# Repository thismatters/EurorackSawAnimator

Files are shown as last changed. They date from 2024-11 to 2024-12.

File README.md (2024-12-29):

# Saw Animator

```
     |\
<--> | \ | <-->
        \|
```

The Saw Animator combines a signal from an LFO with a saw audio signal to produce interesting overtones. In effect the LFO modulates the frequency of the saw wave causing the waveform to dance side-to-side on the oscilloscope. This module has an LFO of its own with adjustable rate, this can be overridden with a different CV signal.

The circuit here is based on the [Yusynth Saw Animator](https://yusynth.net/Modular/EN/SAWANIM/index.html) with minor tweaks to make it more Eurorack friendly. The changes I've made are thus:
* Selected resistors appropriate for +/-12V rails,
* Added polarity protection so that a backward power header doesn't fry anything (twin series schotty diodes: BAT54SL),
* Full surface mount design.

The Yusynth page is a treasure trove of information about this circuit that I am too amateur to claim as my own; please read that outstanding page before using this circuit. The page provides many details and other implementations of this circuit that you may find suitable.

The KiCAD project here uses the library/footprints [found in my companion repo](https://github.com/thismatters/EurorackKiCAD).

## Width

10hp on an Intellijel 1U rack.

## Inputs

Single potentiometer for adjusting LFO rate. Input jack for control voltage which overrides the LFO. Input jack for saw audio signal.

## Outputs

Output jack for animated saw output. LED which tracks the internal LFO.

## Adjustment

### Refine shape

- Ground the LFO input
- Connect a balanced saw wave (+/-5V) to the input
- Connect oscilloscope to the output
- Adjust RV2 (the one in the middle layer) until the triangle looks smooth

###  Set Balance

- Adjust RV1 so that the output is blanaced in the +/-5V range.

## Vendors

There are part numbers in the [BOM](saw-animator.csv) for many of the parts (not for basic passives though) at the following vendors:

* [Mouser](https://www.mouser.com): Needs no introduction. Get your ICs from here (or [digikey](https://www.digikey.com)).
* [Tayda Electronics](https://www.taydaelectronics.com/): Good supplier for passive components; audio jacks, and potentiometers. Their audio jacks are slightly smaller than the thonkiconn from thonk.
* [Love My Switches](https://lovemyswitches.com/): Has [really good knobs](https://lovemyswitches.com/anodized-aluminum-knob-the-lo-fi-1-4-smooth-shaft-12-5mm-od/) to go on those potentiometers!
* [OSHPark](https://oshpark.com/): Fast and (relatively) cheap PCB manufacturer. [V0 PCB](https://oshpark.com/shared_projects/MXBVaxpS)

## Issues

### V0
- The output saw waveshape is slightly distorted at the bottom, the slope is a little off
- Assembly was harder than necessary because the two boards with SMD components did not have enough support tabs to keep them together; each board had to be registered for solder paste application separately.

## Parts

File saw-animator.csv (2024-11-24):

# | Reference | Qty | Value | Footprint | DNP | Vendor | PartNum
1 | C1, C2 | 2 | 22u 50V | Capacitor_THT:CP_Radial_D5.0mm_P2.50mm
2 | C3, C5 | 2 | 100n | Capacitor_SMD:C_0805_2012Metric
3 | C4 | 1 | 100p | Capacitor_SMD:C_0805_2012Metric
4 | C6 | 1 | 2.2u box | Capacitor_THT:C_Rect_L7.2mm_W7.2mm_P5.00mm_FKS2_FKP2_MKS2_MKP2
5 | D1, D2 | 2 | BAT54S | Package_TO_SOT_SMD:SOT-23 |  | Mouser | 863-BAT54SLT1G
6 | D3, D4, D5, D7 | 4 | 1N4148 | Diode_SMD:D_SOD-323_HandSoldering
7 | D6 | 1 | LED_GREEN | LED_THT:LED_D3.0mm
8 | J1 | 1 | Conn_02x05_Odd_Even | Eurorack:PinHeader_2x05_P2.54mm_Vertical |  | Tayda | A-2939
9 | J2, J3, J4 | 3 | Conn_01x03_Socket | Connector_PinSocket_2.54mm:PinSocket_1x03_P2.54mm_Vertical
10 | J5, J6, J7 | 3 | Conn_01x03_Pin | Connector_PinHeader_2.54mm:PinHeader_1x03_P2.54mm_Vertical
11 | J8, J9, J10 | 3 | AudioJack2_SwitchT | Eurorack:AudioJack2_Tayda_A-2566 |  | Tayda | A-2566
12 | Q1 | 1 | BC547 | Package_TO_SOT_THT:TO-92_Inline_Wide |  | Mouser | 637-BC547C
13 | R1, R2 | 2 | 10 | Resistor_SMD:R_0805_2012Metric
14 | R3, R4, R5, R6, R24, R25 | 6 | 100K | Resistor_SMD:R_0805_2012Metric
15 | R7, R8, R9 | 3 | 47K | Resistor_SMD:R_0805_2012Metric
16 | R10, R11, R13, R18 | 4 | 150K | Resistor_SMD:R_0805_2012Metric
17 | R12, R21, R23 | 3 | 22K | Resistor_SMD:R_0805_2012Metric
18 | R14 | 1 | 1K | Resistor_SMD:R_0805_2012Metric
19 | R15 | 1 | 120K | Resistor_SMD:R_0805_2012Metric
20 | R16 | 1 | 220K | Resistor_SMD:R_0805_2012Metric
21 | R17, R20 | 2 | 15K | Resistor_SMD:R_0805_2012Metric
22 | R19 | 1 | 1.5K | Resistor_SMD:R_0805_2012Metric
23 | R22 | 1 | 4.7K | Resistor_SMD:R_0805_2012Metric
24 | RV1 | 1 | 100K | Potentiometer_THT:Potentiometer_Bourns_3296W_Vertical
25 | RV2 | 1 | C1M | Eurorack:Potentiometer_RV16AF-41-15R1
26 | RV3 | 1 | 500K | Potentiometer_THT:Potentiometer_Bourns_3006P_Horizontal
27 | U1, U2 | 2 | TL074 | Package_SO:SOIC-14_3.9x8.7mm_P1.27mm |  | Mouser | 595-TL074CDR

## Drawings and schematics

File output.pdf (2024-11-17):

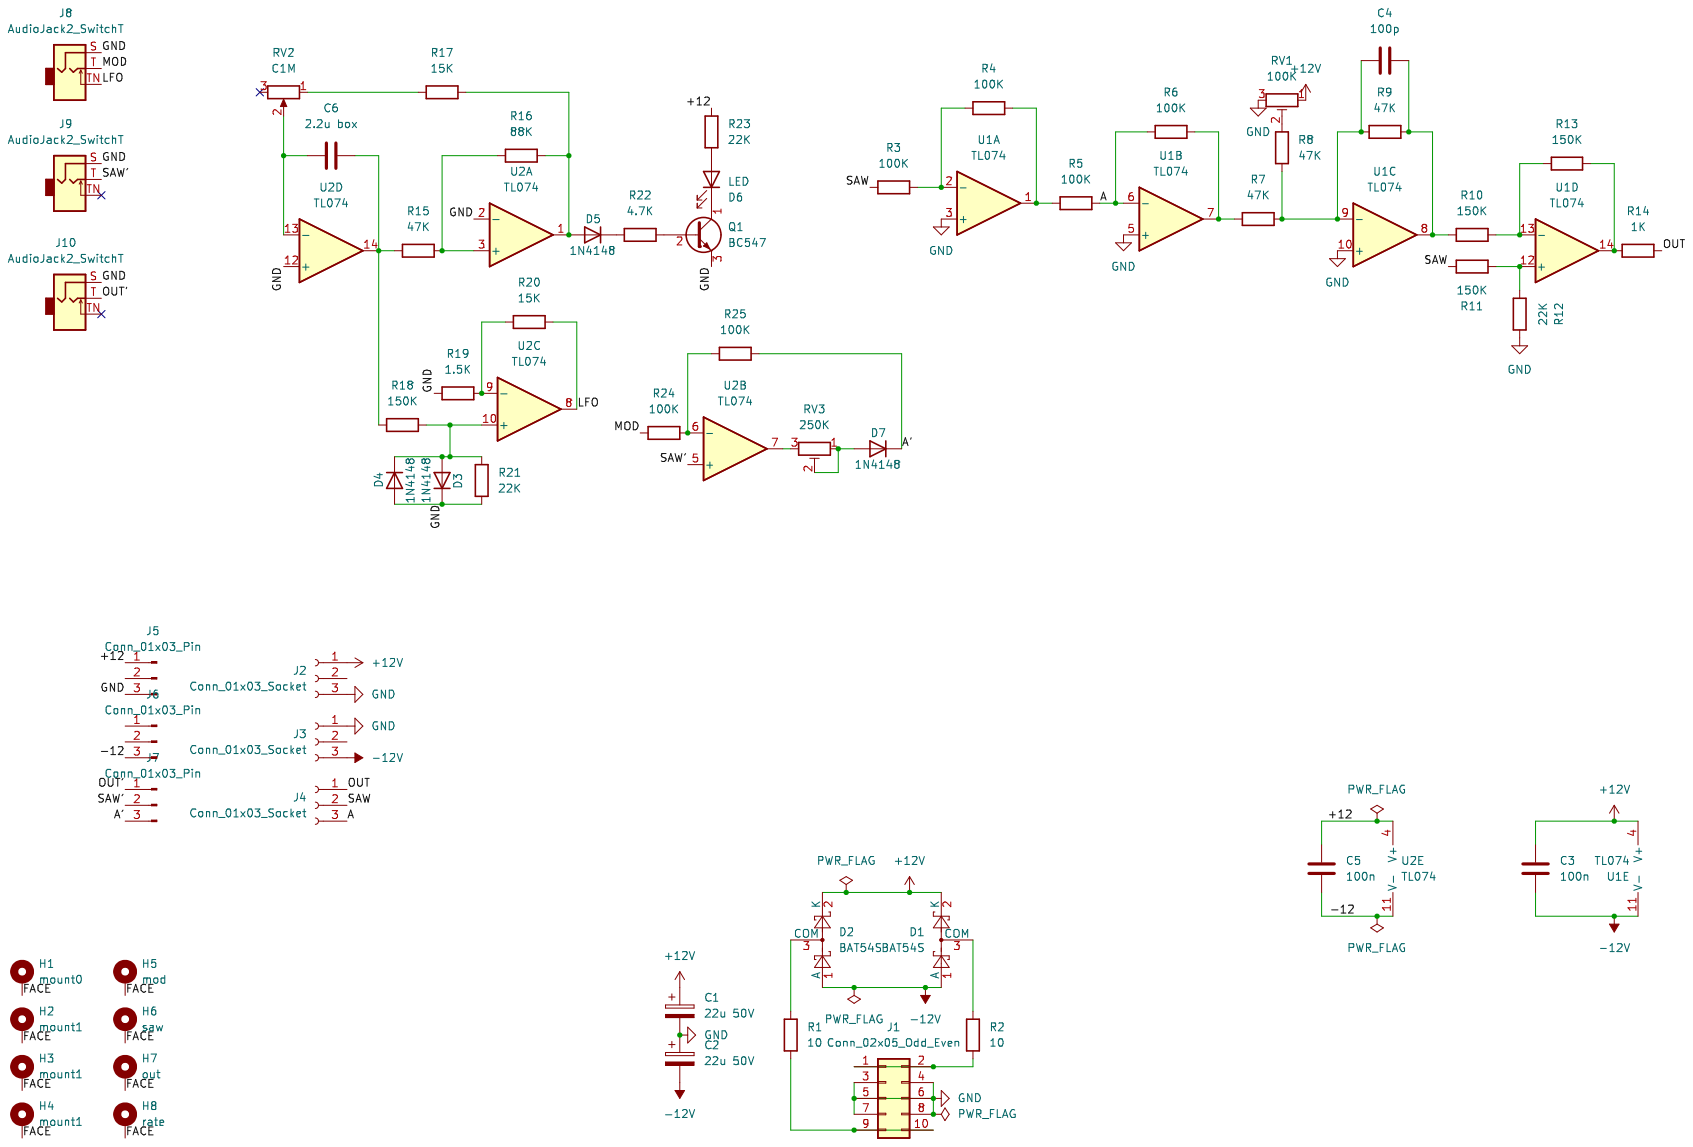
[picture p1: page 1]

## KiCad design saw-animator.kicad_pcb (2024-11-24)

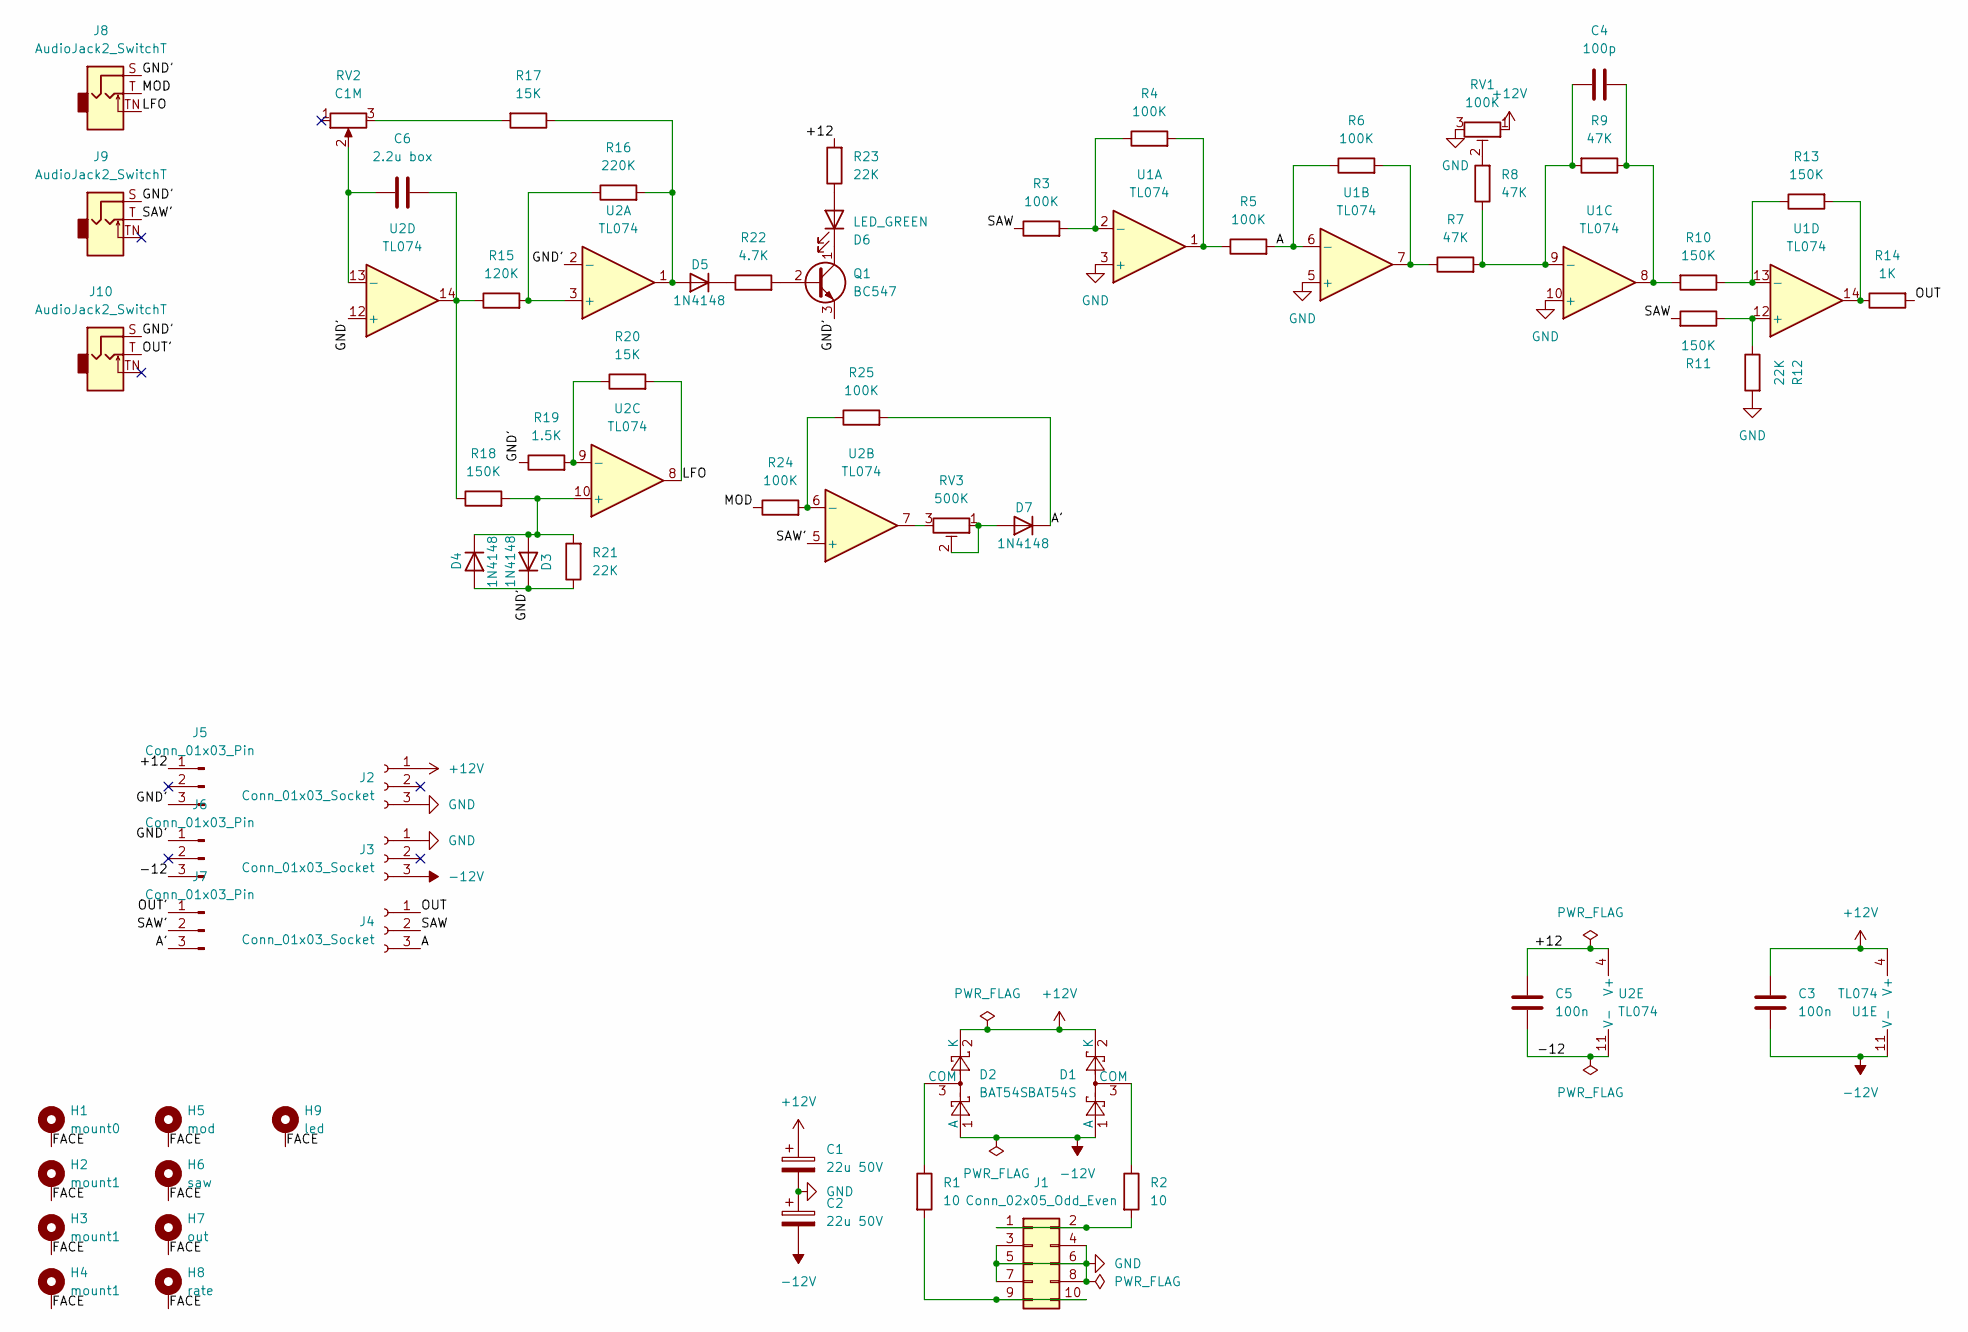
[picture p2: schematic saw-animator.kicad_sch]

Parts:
C1, C2: 22u 50V; CP_Radial_D5.0mm_P2.50mm
C3, C5: 100n; C_0805_2012Metric
C4: 100p; C_0805_2012Metric
C6: 2.2u box; C_Rect_L7.2mm_W7.2mm_P5.00mm_FKS2_FKP2_MKS2_MKP2
D1, D2: BAT54S; SOT-23; PartNum 863-BAT54SLT1G
D3, D4, D5, D7: 1N4148; D_SOD-323_HandSoldering
D6: LED_GREEN; LED_D3.0mm
H1: mount0; Mech-MountingHole
H2, H3, H4: mount1; Mech-MountingHole
H5: mod; Mech-AudioJack-Hole-Input-CV
H6: saw; Mech-AudioJack-Hole-Input
H7: out; Mech-AudioJack-Hole-Output
H8: rate; Mech-Potentiometer-Hole_level_90deg
H9: led; Mech-LED-Hole-3mm-Bezel
J1: Conn_02x05_Odd_Even; PinHeader_2x05_P2.54mm_Vertical; PartNum A-2939
J2, J3, J4: Conn_01x03_Socket; PinSocket_1x03_P2.54mm_Vertical
J5, J6, J7: Conn_01x03_Pin; PinHeader_1x03_P2.54mm_Vertical
J8, J9, J10: AudioJack2_SwitchT; AudioJack2_Tayda_A-2566; PartNum A-2566
Q1: BC547; TO-92_Inline_Wide; PartNum 637-BC547C
R1, R2: 10; R_0805_2012Metric
R3, R4, R5, R6, R24, R25: 100K; R_0805_2012Metric
R7, R8, R9: 47K; R_0805_2012Metric
R10, R11, R13, R18: 150K; R_0805_2012Metric
R12, R21, R23: 22K; R_0805_2012Metric
R14: 1K; R_0805_2012Metric
R15: 120K; R_0805_2012Metric
R16: 220K; R_0805_2012Metric
R17, R20: 15K; R_0805_2012Metric
R19: 1.5K; R_0805_2012Metric
R22: 4.7K; R_0805_2012Metric
RV1: 100K; Potentiometer_Bourns_3296W_Vertical
RV2: C1M; Potentiometer_RV16AF-41-15R1
RV3: 500K; Potentiometer_Bourns_3006P_Horizontal
U1, U2: TL074; SOIC-14_3.9x8.7mm_P1.27mm; PartNum 595-TL074CDR

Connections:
+12V: C1.1, C3.1, D1.2 (K), D2.2 (K), J2.1, RV1.1, U1.4 (V+)
-12V: C2.2, C3.2, D1.1 (A), D2.1 (A), J3.3, U1.11 (V-)
/+12: C5.1, J5.1, R23.2, U2.4 (V+)
/-12: C5.2, J6.3, U2.11 (V-)
/A: J4.3, R5.2, R6.1, U1.6 (-)
/A': D7.1 (K), J7.3, R25.2
/FACE: H1.1, H2.1, H3.1, H4.1, H5.1, H6.1, H7.1, H8.1, H9.1
/GND': D3.1 (K), D4.2 (A), J5.3, J6.1, J8.S, J9.S, J10.S, Q1.3 (E), R19.1, R21.1, U2.2 (-), U2.12 (+)
/LFO: J8.TN, R20.2, U2.8
/MOD: J8.T, R24.1
/OUT: J4.1, R14.2
/OUT': J7.1, J10.T
/SAW: J4.2, R3.1, R11.2
/SAW': J7.2, J9.T, U2.5 (+)
GND: C1.2, C2.1, J1.3, J1.4, J1.5, J1.6, J1.7, J1.8, J2.3, J3.1, R12.2, RV1.3, U1.3 (+), U1.5 (+), U1.10 (+)
unnamed: C4.2, R9.1, R10.2, U1.8
unnamed: C6.2, R15.1, R18.1, U2.14
unnamed: D1.3 (COM), R2.1
unnamed: D2.3 (COM), R1.1
unnamed: D3.2 (A), D4.1 (K), R18.2, R21.2, U2.10 (+)
unnamed: D5.2 (A), R16.2, R17.1, U2.1
unnamed: D5.1 (K), R22.1
unnamed: D6.2 (A), R23.1
unnamed: D6.1 (K), Q1.1 (C)
unnamed: D7.2 (A), RV3.1, RV3.2
unnamed: J1.1, J1.2, R2.2
unnamed: J1.9, J1.10, R1.2
unnamed: Q1.2 (B), R22.2
unnamed: R4.2, R5.1, U1.1
unnamed: R6.2, R7.1, U1.7
unnamed: R8.2, RV1.2
unnamed: R13.2, R14.1, U1.14
unnamed: R17.2, RV2.3
unnamed: RV3.3, U2.7
unnamed: R3.2, R4.1, U1.2 (-)
unnamed: C4.1, R7.2, R8.1, R9.2, U1.9 (-)
unnamed: R11.1, R12.1, U1.12 (+)
unnamed: R10.1, R13.1, U1.13 (-)
unnamed: R15.2, R16.1, U2.3 (+)
unnamed: R24.2, R25.1, U2.6 (-)
unnamed: R19.2, R20.1, U2.9 (-)
unnamed: C6.1, RV2.2, U2.13 (-)

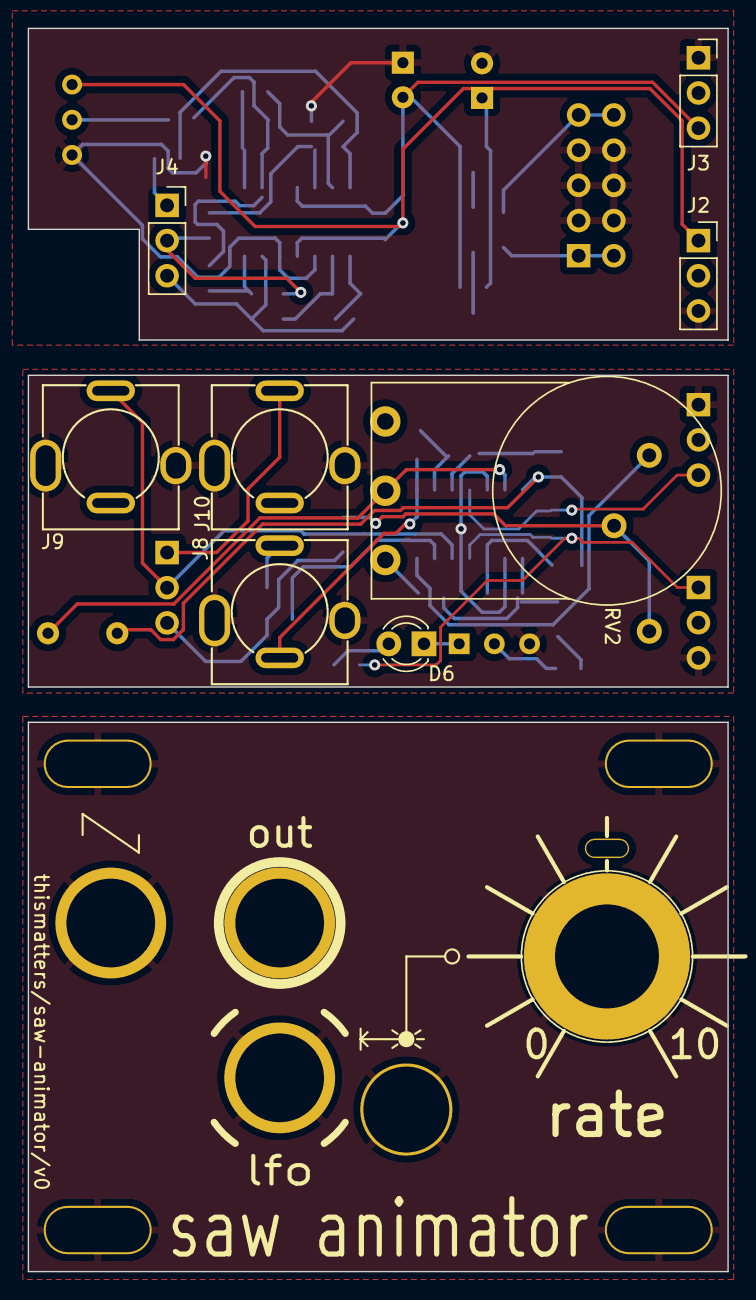
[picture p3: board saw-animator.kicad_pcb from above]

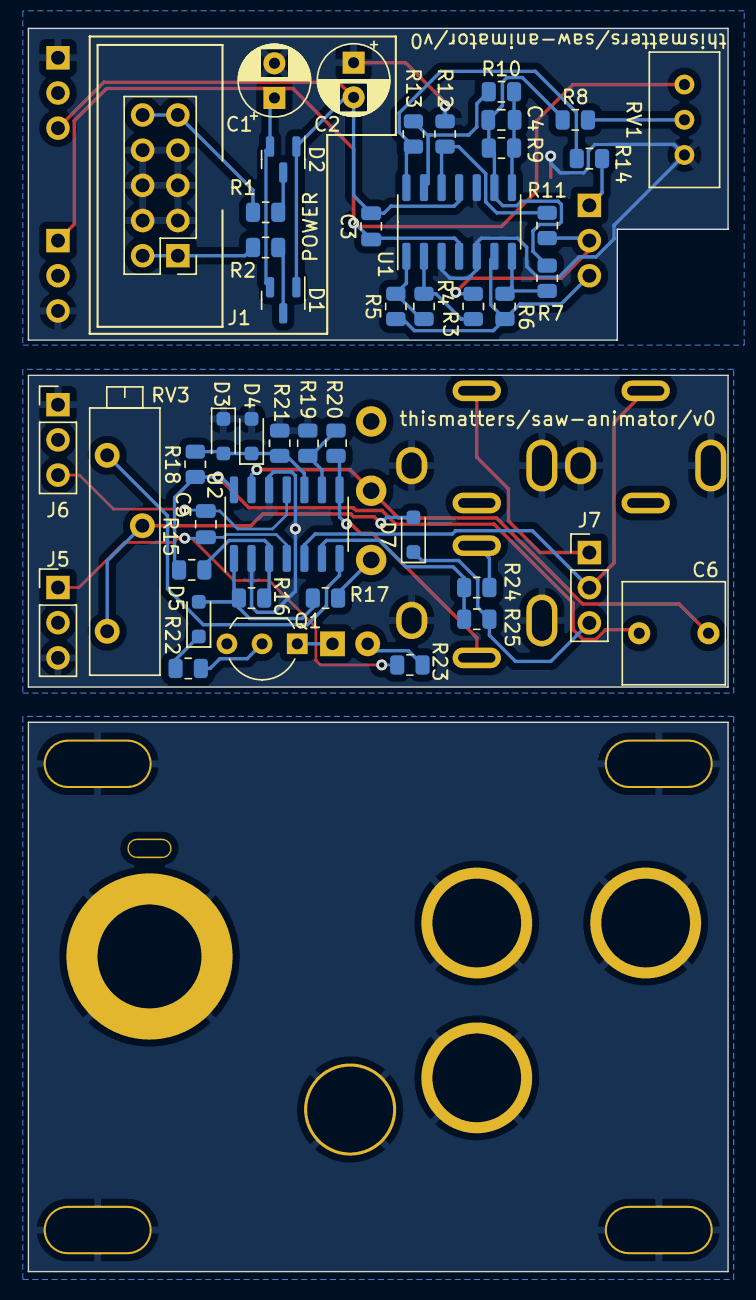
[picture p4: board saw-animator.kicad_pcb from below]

Board: 2 copper layers, 50.5 x 89.7 mm, 63 parts (46 on the bottom side), 42 nets.

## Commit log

2024-11-17 prototyped and tested ready for v0 manu
    [saw-animator.csv, saw-animator.kicad_pcb, saw-animator.kicad_sch]
2024-11-24 fix: updating resistances to easily obtainable values
    [saw-animator.csv, saw-animator.kicad_pcb, saw-animator.kicad_sch]
